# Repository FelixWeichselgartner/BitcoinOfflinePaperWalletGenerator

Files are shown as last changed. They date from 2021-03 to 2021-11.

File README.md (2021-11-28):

# Bitcoin Offline Paper-Wallet Generator

You ever felt unsafe creating a Bitcoin wallet on your desktop computer or on your smartphone? As such devices are often connected to the internet there might be a chance you have already been hacked and somebody could be stealing your private key(s). The solution is to create your private keys on a device that cannot be hacked because it is not connected to any other devices (e.g. no internet, ...). 

This project aims for a microcontroller-based private key generation. The private key will be generated using rng. Your bitcoin address will then be calculated from your private key. Both will then be displayed on a display, for you to transfer on a piece of paper, which you will keep save. You can now use the address to transfer your bitcoins. Once you need your bitcoins, you simply import your private key in a wallet program and for safety reasons create a new paper wallet with this device. You can then use the bitcoins you need and transfer the rest to your new save bitcoin address.

## Work in progress

Only use this project at your own risk. I am not responsible for your usage of this code. Furthermore, do not send bitcoins to any addresses in this repo.

## Breadboard testbench

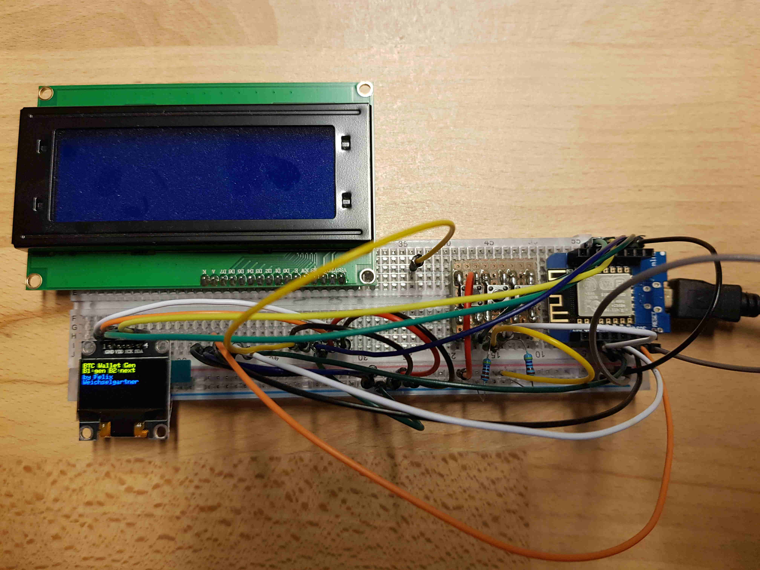
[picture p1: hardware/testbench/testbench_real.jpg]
testbench_real


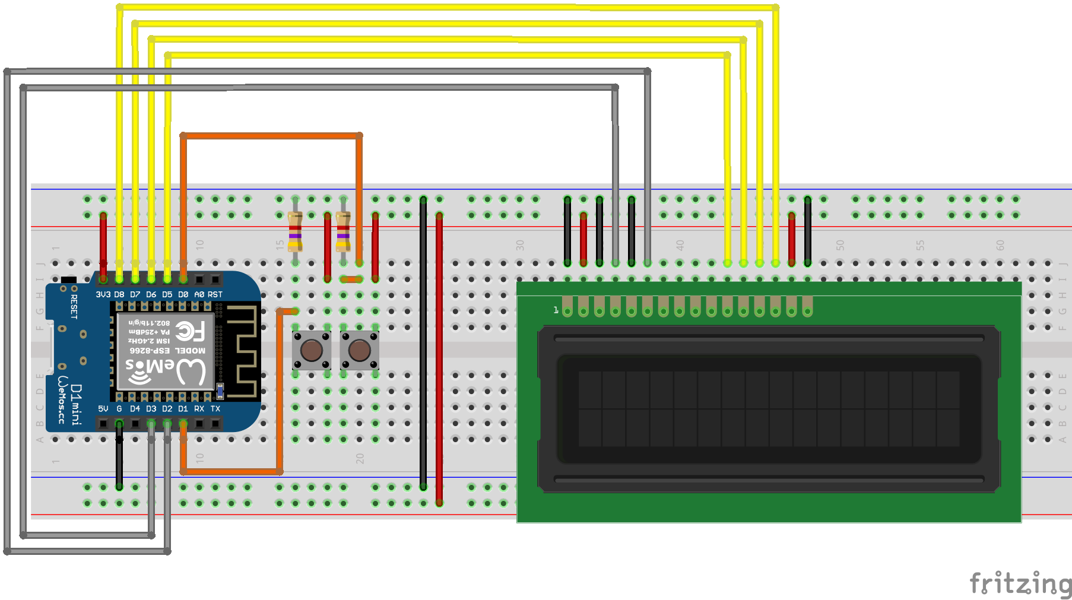
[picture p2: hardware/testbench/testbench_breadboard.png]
testbench_img


## PCB

Click [here](documentation/flash_pcb.md) to see how to flash a pcb.

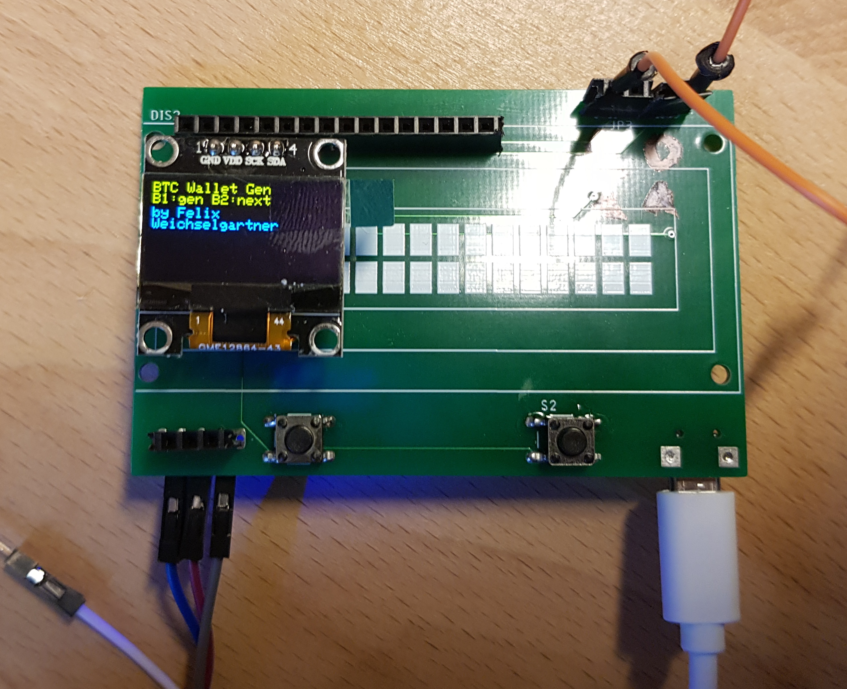
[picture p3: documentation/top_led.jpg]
pcb_top


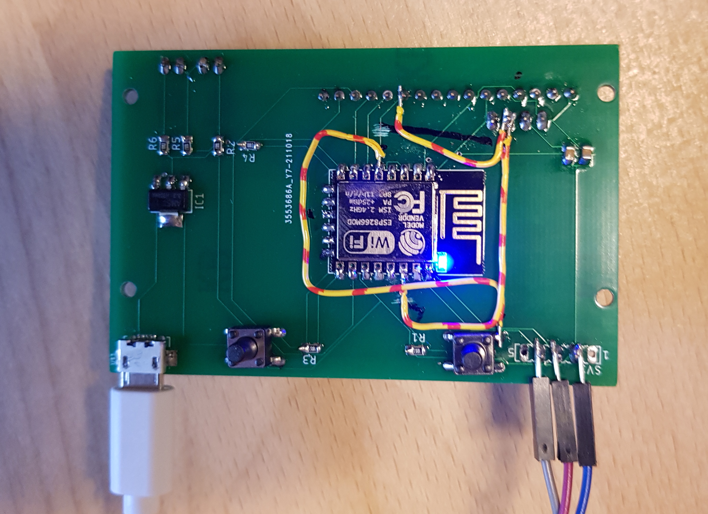
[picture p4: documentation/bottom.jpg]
pcb_bottom


The wires are for my revision 1 board and are already fixed in the schematic.

## RNG tests

Click [here](tests/rng_validation/TEST.md) to see the RNG tests.

## Dependencies

You can download all neccessary firmware libraries by executing `sh firmware/lib/download.sh`.

Firmware:
* https://github.com/micro-bitcoin/uBitcoin (MIT)
* https://github.com/marvinroger/ESP8266TrueRandom.git (LGPL-3.0 if ESP8266 is used)
* https://github.com/adafruit/Adafruit_BusIO (MIT, for SSD1306 display)
* https://github.com/adafruit/Adafruit-GFX-Library (BSD, for SSD1306 display)
* https://github.com/adafruit/Adafruit_SSD1306 (BSD, for SSD1306 display)

Only for address validation:
* https://github.com/PaulGregor/Bitcoin-Keys-Generator (GPL-3.0)

## License

This project is licensed under `gnu-gpl-v3.0`. See `License.txt` for more information.

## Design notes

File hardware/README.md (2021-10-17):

# Hardware

## Testbench

tb

## PCB

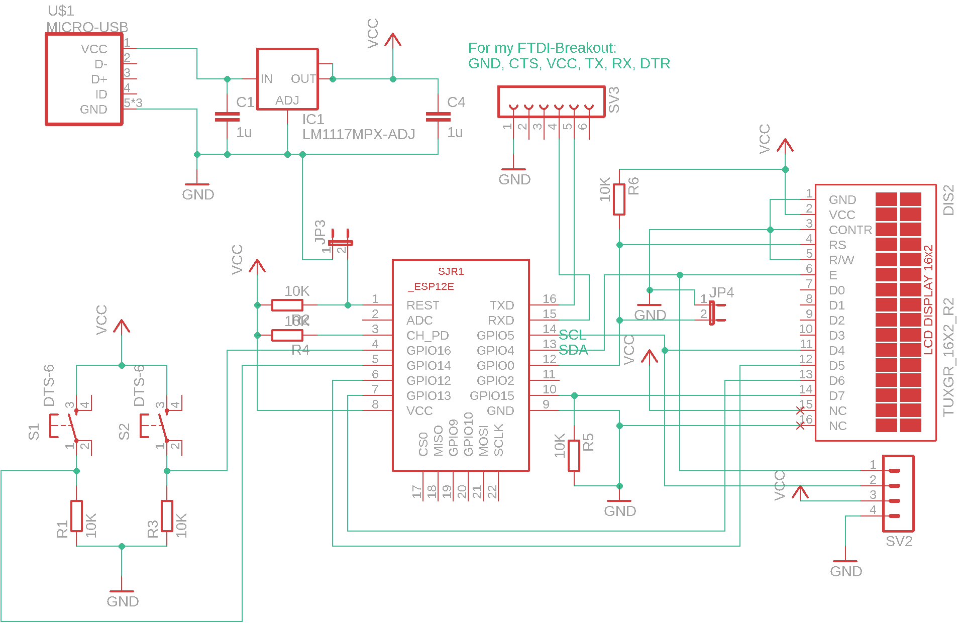
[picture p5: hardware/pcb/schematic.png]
schem


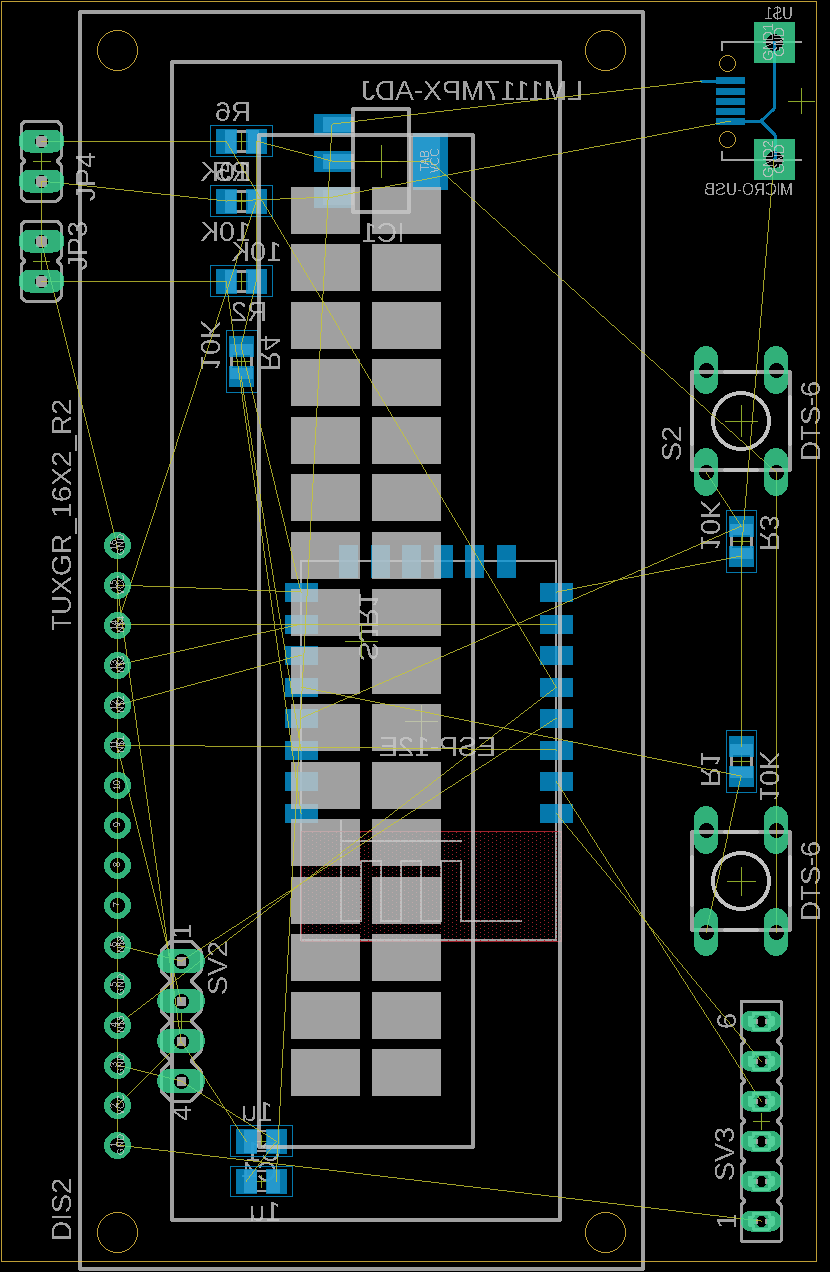
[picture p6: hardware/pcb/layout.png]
layout


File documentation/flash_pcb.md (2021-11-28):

# How to flash a pcb

Here is a preview of the pcbs. You can choose between a lcd and a led display.

In the top right you see two orange wires. The right wire is connected to GPIO0 and the left one to RESET. With the jumpers you can connect both pins to GND.

pcb_top_led

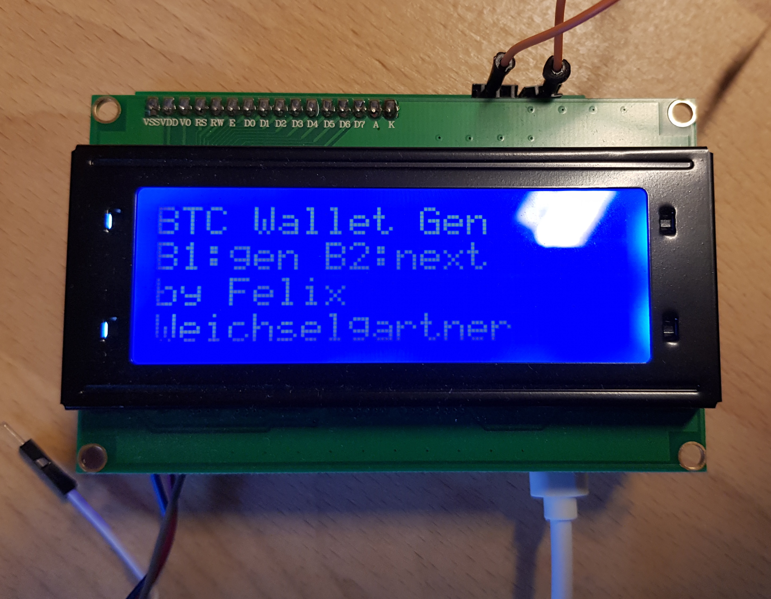
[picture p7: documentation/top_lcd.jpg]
pcb_top_lcd


If you use the lcd display, it is not possible to connect the ftdi-programmer to the jumpers. I simply soldered them to the back.

pcb_bottom

The wires are for my revision 1 board and are already fixed in the schematic.

# Steps for uploading

* Connect your FTDI-Breakout board according to the schematic
* Connect GPIO0 with the jumper to GND
* Connect RST with the jumper to GND
* Disconnect RST with the jumper from GND
* The built-in led should have turned off
* Now the ESP-12E module should be in programming mode
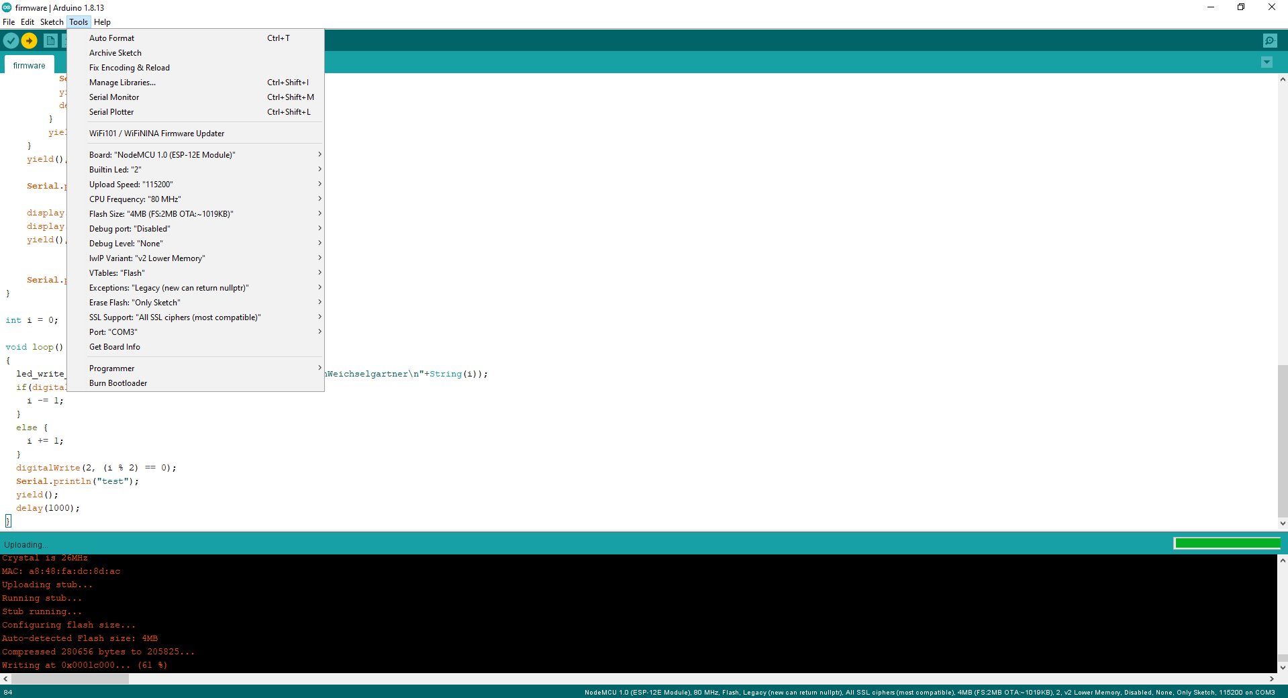
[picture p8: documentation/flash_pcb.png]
flash_settings
* 
    * Choose these settings
* Press upload
* Disconnect GPIO0 with the jumper from GND
* Connect RST with the jumper to GND
* Disconnect RST with the jumper from GND
* The program should be running now

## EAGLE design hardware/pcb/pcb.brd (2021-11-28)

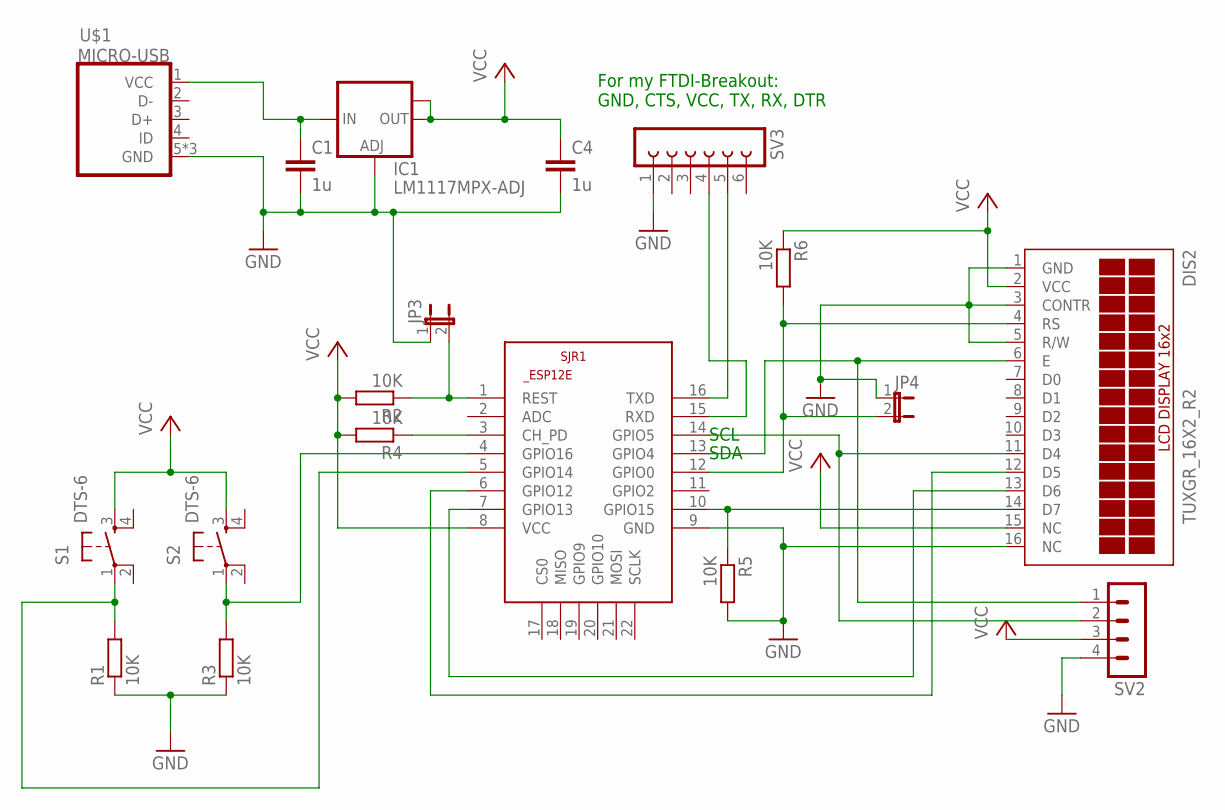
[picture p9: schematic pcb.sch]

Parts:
C1, C4: 1u; C0805
DIS2: TUXGR_16X2_R2
IC1: LM1117MPX-ADJ; SOT223
JP3, JP4: JP1E; JP1
R1, R2, R3, R4, R5, R6: 10K; R0805
S1, S2: DTS-6
SJR1: ESP8266-12EESP12E; ESP8266-ESP12E
SV2: MA04-1
SV3: FE06-1; FE06
U$1: MICRO-USB

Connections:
GND: C1.2, C4.2, DIS2.1 (GND), DIS2.3 (CONTR), DIS2.5 (R/W), DIS2.16 (NC), IC1.1 (ADJ), JP3.1, JP4.1, R1.1, R3.1, R5.2, SJR1.9 (GND), SV2.4, SV3.1, U$1.5 (GND), U$1.GND1 (GND), U$1.GND2 (GND)
unnamed: DIS2.11 (D4), SJR1.14 (GPIO5), SV2.2
unnamed: DIS2.12 (D5), SJR1.6 (GPIO12)
unnamed: DIS2.13 (D6), SJR1.7 (GPIO13)
unnamed: DIS2.14 (D7), R5.1, SJR1.10 (GPIO15)
unnamed: DIS2.4 (RS), JP4.2, R6.2, SJR1.12 (GPIO0)
unnamed: R3.2, S2.1, SJR1.4 (GPIO16)
unnamed: R1.2, S1.1, SJR1.5 (GPIO14)
unnamed: DIS2.6 (E), SJR1.13 (GPIO4), SV2.1
unnamed: SJR1.15 (RXD), SV3.4
unnamed: SJR1.16 (TXD), SV3.5
unnamed: C1.1, IC1.3 (IN), U$1.1 (VCC)
unnamed: JP3.2, R2.1, SJR1.1 (REST)
unnamed: R4.1, SJR1.3 (CH_PD)
VCC: C4.1, DIS2.2 (VCC), DIS2.15 (NC), IC1.2 (OUT), IC1.TAB (OUT1), R2.2, R4.2, R6.1, S1.3, S2.3, SJR1.8 (VCC), SV2.3

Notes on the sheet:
SDA
SCL
For my FTDI-Breakout: GND, CTS, VCC, TX, RX, DTR

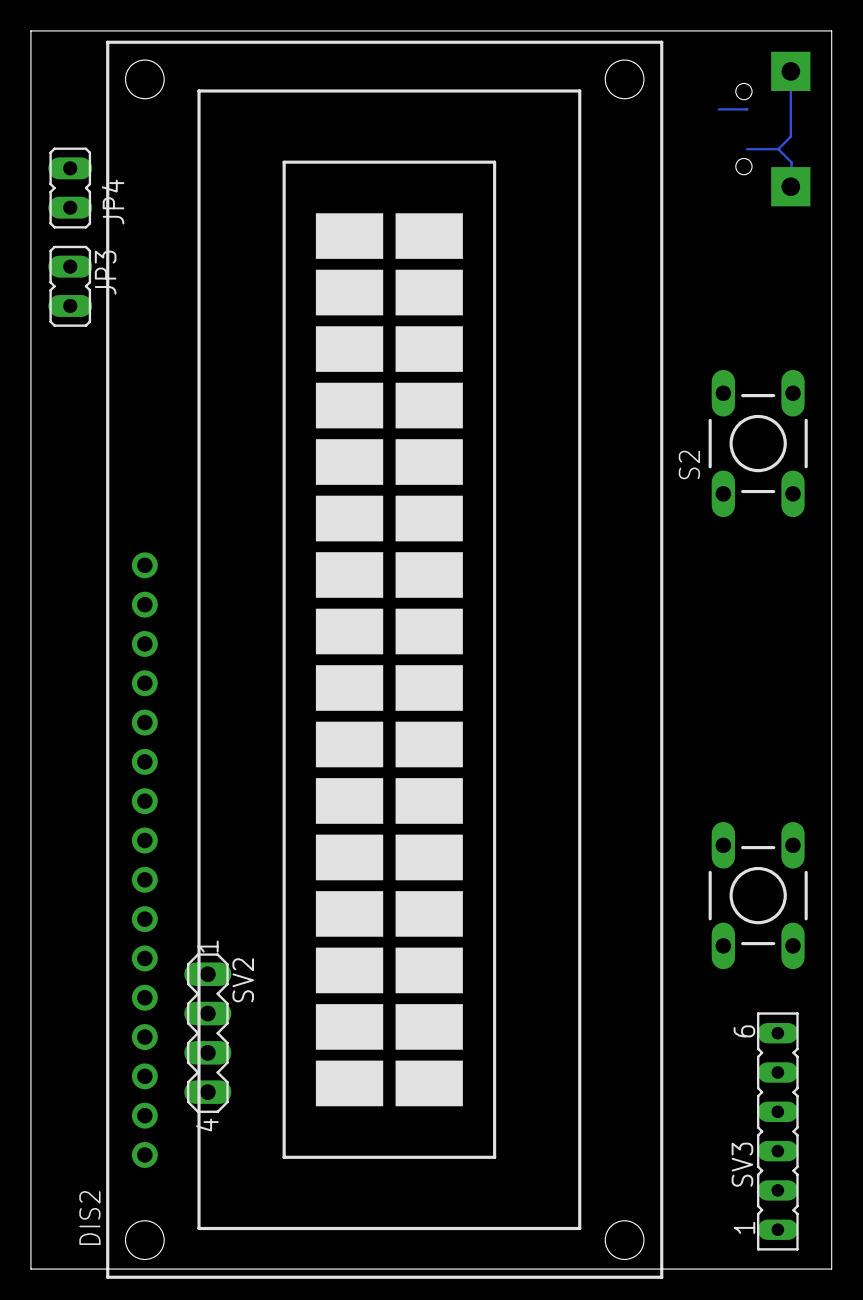
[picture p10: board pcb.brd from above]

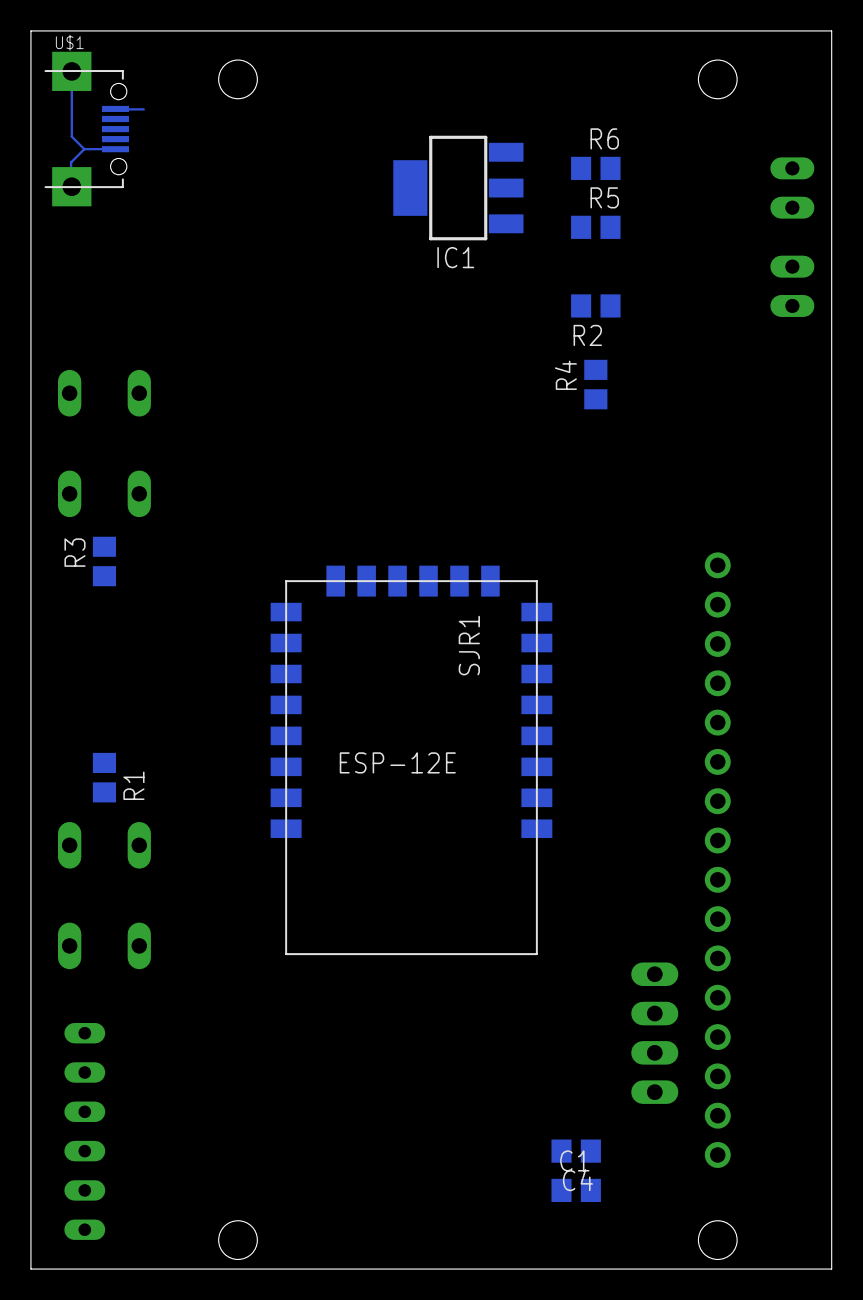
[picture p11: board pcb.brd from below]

Board: 2 copper layers, 51.7 x 80.0 mm, 18 parts (11 on the bottom side), 15 nets.

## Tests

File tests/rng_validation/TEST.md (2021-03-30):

# Here are some information on the RNG

Here you can verify the random number generation. Before you use the system make sure you understand how the numbers are generated and whether you agree with the process. I'm not an expert in random number generation and it might be possible that there is an obvious mistake that others can abuse to generate similar numbers to yours, which might lead to generating the same private key. I am not responsible if your private key gets reproduced!

## ESP8266

Random number generation for the ESP8266 is done with https://github.com/marvinroger/ESP8266TrueRandom.git. I did not verify if the random number are truly random, i.e. that they dont repeat with a given seed. However, I did test the distribution of the random numbers:

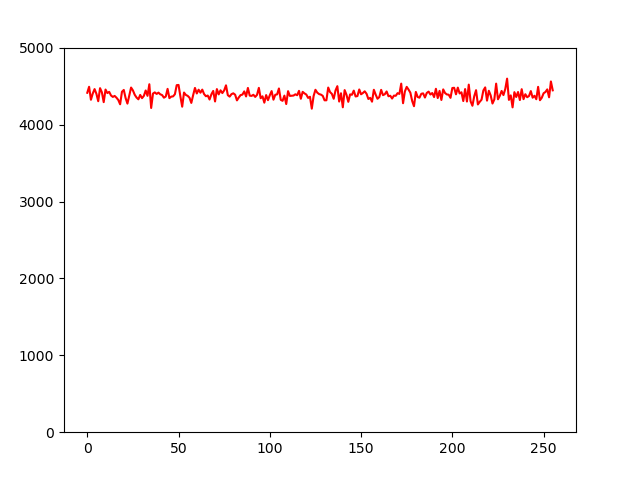
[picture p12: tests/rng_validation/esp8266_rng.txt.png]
distribution_plot


This is fine as only about 100'000 numbers are tested.

## STM32

Not tested so far.

## All tested microcontrollers

You can check the amount of samples and the actual numbers for each value from 0 to 255 in the file: `output.txt`.

## Reproduce this yourself

You can use the rng_test sketch to print random numbers to the serial monitor. Then press `Ctrl + a` to select everything and copy it to a text file. Then include the text file in `test.py`.

## TODO:

Once could use the random generated numbers and check for patterns in the generations, e.g. to cehck for repeating numbers to check that there is actual true random number generation.

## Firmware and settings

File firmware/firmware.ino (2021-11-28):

#include <Bitcoin.h>
#include <stdint.h>

int button1 = 14;
int button2 = 16;

//#define LCD_DISPLAY

#ifdef LCD_DISPLAY
#include <LiquidCrystal.h>
const int PIN_RS = 0, PIN_E = 4, PIN_D4 = 5, PIN_D5 = 12, PIN_D6 = 13, PIN_D7 = 15;
LiquidCrystal lcd(PIN_RS, PIN_E, PIN_D4, PIN_D5, PIN_D6, PIN_D7);
#else
#include <SPI.h>
#include <Wire.h>
#include <Adafruit_GFX.h>
#include <Adafruit_SSD1306.h>

#define SCREEN_WIDTH 128 // OLED display width, in pixels
#define SCREEN_HEIGHT 64 // OLED display height, in pixels

// Declaration for an SSD1306 display connected to I2C (SDA, SCL pins)
// The pins for I2C are defined by the Wire-library. 
#define OLED_RESET     -1 // Reset pin # (or -1 if sharing Arduino reset pin)
#define SCREEN_ADDRESS 0x3C ///< See datasheet for Address; 0x3D for 128x64, 0x3C for 128x32
Adafruit_SSD1306 display(SCREEN_WIDTH, SCREEN_HEIGHT, &Wire, OLED_RESET);
#endif

#ifdef ESP8266
#include <ESP8266TrueRandom.h>
#endif

#define DEBUG

PrivateKey pk;
PublicKey pubk;
bool no_wallet_created_so_far = true;
String pkstr = "", pkwif = "", pubkstr = "";

int led_board = LED_BUILTIN;

uint8_t generate_random_8bit()
{
#ifdef ESP32
    // this is actually untested.
    return (uint8_t)esp_random();
#elif defined(ESP8266)
    return (uint8_t)ESP8266TrueRandom.randomByte();
#else
    // attention: this is pseudo random - do not use for actual wallet generation.
    return random(256);
#endif
}

#ifdef LCD_DISPLAY
#else
void led_write_text(String text) {
    display.clearDisplay();

    display.setTextSize(1);      // Normal 1:1 pixel scale
    display.setTextColor(SSD1306_WHITE); // Draw white text
    display.setCursor(0, 0);     // Start at top-left corner
    display.cp437(true);         // Use full 256 char 'Code Page 437' font

    display.write(text.c_str());
    //display.write("Test by Felix Weichselgartner, Habe nun, ach! Philosophie, Juristerei and Medizin, Und leider auch Theologie Durchaus studiert, mit heißem Bemühn. Da steh' ich nun, X");

    display.display();
}
#endif

void setup()
{
    // setup leds
    pinMode(led_board, OUTPUT);
    // setup buttons
    pinMode(button1, INPUT);
    pinMode(button2, INPUT);

#ifdef LCD_DISPLAY
    // setup lcd
    lcd.begin(20, 4);
#else
    // SSD1306_SWITCHCAPVCC = generate display voltage from 3.3V internally
    if(!display.begin(SSD1306_SWITCHCAPVCC, SCREEN_ADDRESS)) {
        Serial.println(F("SSD1306 allocation failed"));
        for(;;); // Don't proceed, loop forever
    }

    display.clearDisplay();
    display.display();
#endif


#ifdef DEBUG
    // set up serial if in debug mode
    Serial.begin(9600);
    // wait until serial is connected.
    while (!Serial)
        ;
    Serial.println("starting program");
#endif

    // setup random number generation
#ifdef ESP32
    bootloader_random_enable();
#else
    randomSeed(analogRead(0));
#endif
}

// generate private key and public address
void generate_wallet()
{
    const uint8_t pklen = 32;
    uint8_t pkbytes[pklen];

    for (uint8_t i = 0; i < pklen; i++)
    {
        pkbytes[i] = generate_random_8bit();
    }

    pkstr = "";
    for (uint8_t i = 0; i < pklen; i++)
    {
        if (pkbytes[i] <= 0x0f)
        {
            pkstr += "0";
        }
        pkstr += String(pkbytes[i], HEX);
    }

    pk = PrivateKey(pkbytes);

    pkwif = pk.wif();
    pubk = pk.publicKey();
    pubkstr = pubk.nestedSegwitAddress();

#ifdef DEBUG
    // send data to serial bus if on debug mode
    Serial.println("private key: " + pkstr);
    Serial.println("private key wif: " + pk.wif());
    Serial.println("public key nestedSwegwit:");
    //Serial.println(pubk.legacyAddress());
    //Serial.println(pubk.segwitAddress());
    Serial.println(pubk.nestedSegwitAddress());
    Serial.println("wallet created.");
#endif
}

int action = 1;
// action = 0 ==> don't update lcd
// action = 1 ==> init show info
// action = 2 ==> next page
// action = 3 ==> update wallet
int page = 1;
int edge_detector_create_wallet = LOW, edge_detector_lcd = LOW;

void loop()
{
    switch (action)
    {
    case 0:
        break;
    case 1:
#ifdef LCD_DISPLAY
        lcd.clear();
        lcd.setCursor(0, 0);
        //         01234567890123456789
        lcd.print("BTC Wallet Gen");
        lcd.setCursor(0, 1);
        lcd.print("B1:gen B2:next");
        lcd.setCursor(0, 2);
        lcd.print("by Felix");
        lcd.setCursor(0, 3);
        lcd.print("Weichselgartner");
#else
        led_write_text("BTC Wallet Gen\nB1:gen B2:next\nby Felix\nWeichselgartner");
#endif
        break;
    case 2:
        if (page == 1)
        {
            page = 2;
        }
        else
        {
            page = 1;
        }
    case 3:
        // display private key (in wif): pkwif (pkstr - optional)
        // display public address for user: pubkstr
        // on lcd display
        if (!no_wallet_created_so_far)
        {
            if (page == 1)
            {
#ifdef LCD_DISPLAY
                lcd.clear();
                lcd.setCursor(0, 0);
                //         01234567890123456789
                //         --------------------
                //         --------------------
                //         ------------
                lcd.print("Wallet Import Format");
                lcd.setCursor(0, 1);
                String line1 = pkwif.substring(0, 20);
                lcd.print(line1);
                lcd.setCursor(0, 2);
                String line2 = pkwif.substring(20, 40);
                lcd.print(line2);
                lcd.setCursor(0, 3);
                String line3 = pkwif.substring(40);
                lcd.print(line3);
#else
                led_write_text("Wallet Import Format\n" + pkwif);
#endif
            }
            else
            {
#ifdef LCD_DISPLAY
                lcd.clear();
                lcd.setCursor(0, 0);
                //         01234567890123456789
                //         --------------------
                //         --------------
                //         L5jRJp7NnLn6Koc51Ly6
                //         FiGdtBA8dkNd4XCFHLbK
                //         wXkrHs3BTA5n

                lcd.print("Public Key");
                lcd.setCursor(0, 1);
                String line1p = pubkstr.substring(0, 20);
                lcd.print(line1p);
                lcd.setCursor(0, 2);
                String line2p = pubkstr.substring(20);
                lcd.print(line2p);
#else
                led_write_text("Public Key\n" + pubkstr);
#endif
            }
        }

        break;
    }

    action = 0;

    // catch buttons

    int button2_state = digitalRead(button2);
    // create wallet button
    if (button2_state != edge_detector_create_wallet && button2_state == HIGH)
    {
        action = 2;
    }

    edge_detector_create_wallet = button2_state;

    int button1_state = digitalRead(button1);
    // next page on lcd button
    if (button1_state != edge_detector_lcd && button1_state == HIGH)
    {
        no_wallet_created_so_far = false;
        generate_wallet();
        action = 3;
    }

    edge_detector_lcd = button1_state;
}

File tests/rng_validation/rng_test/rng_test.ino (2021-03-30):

#include <stdint.h>

#ifdef ESP8266
#include <ESP8266TrueRandom.h>
#endif


uint8_t generate_random_8bit()
{
#ifdef ESP32
    return (uint8_t)esp_random();
#elif defined(ESP8266)
    return (uint8_t)ESP8266TrueRandom.randomByte();
#else
    // attention: this is pseudo random - do not use for actual wallet generation.
    return random(256);
#endif
}

void setup()
{
    Serial.begin(115200);
    Serial.println("starting");

#ifdef ESP32
    bootloader_random_enable();
#else
    randomSeed(analogRead(0));
#endif
}

void loop()
{
    uint8_t rn = generate_random_8bit();
    Serial.println(rn);
}

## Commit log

2021-03-30 included testbench breadboard schematic
    [testbench.fzz]
2021-08-03 wemos d1 v2 version
    [testbench.fzz]
2021-08-04 testbench working
    [testbench.fzz]
2021-08-04 layout for pcb milling
    [testbench.fzz]
2021-08-04 move wiring to bottom layer
    [testbench.fzz]
2021-10-17 eagle pcb
    [pcb.brd, pcb.sch, testbench.fzz]
2021-10-31 added support for new new display
    [pcb.brd]
2021-11-28 debugged pcb, which is now working
    [pcb.brd, pcb.sch]
